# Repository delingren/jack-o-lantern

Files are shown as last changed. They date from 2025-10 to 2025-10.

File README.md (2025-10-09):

# Jack-O-Lantern (3d printed, powered by USB)

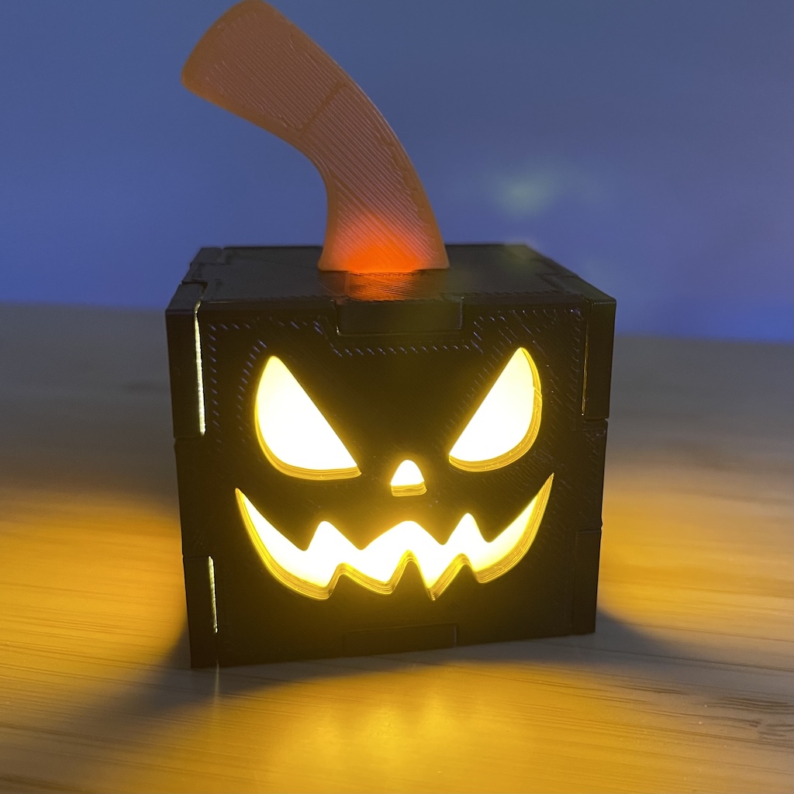
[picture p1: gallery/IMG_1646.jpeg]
black


## Parts:

* Soldering iron and tin
* 3D printer
* COB LED light [AliExpress](https://www.aliexpress.us/item/3256807134620275.html) | [Amazon](https://www.amazon.com/dp/B07DHB13J4)
* USB-C breakout board [AliExpress](https://www.aliexpress.us/item/3256809276708466.html) | [Amazon](https://www.amazon.com/dp/B0F2S1K5X8)
* 22 ohm resistor (or similar value)
* Orange vellum paper (if you print black)
* Double sided tape, super glue, paper glue, 
* Optinal: hot glue and glue gun

## Steps

There isn't much to it once you have 3d printed everything. 

0. 3D print all the pieces

1. Solder the resister, USB breakout board, and the LED together

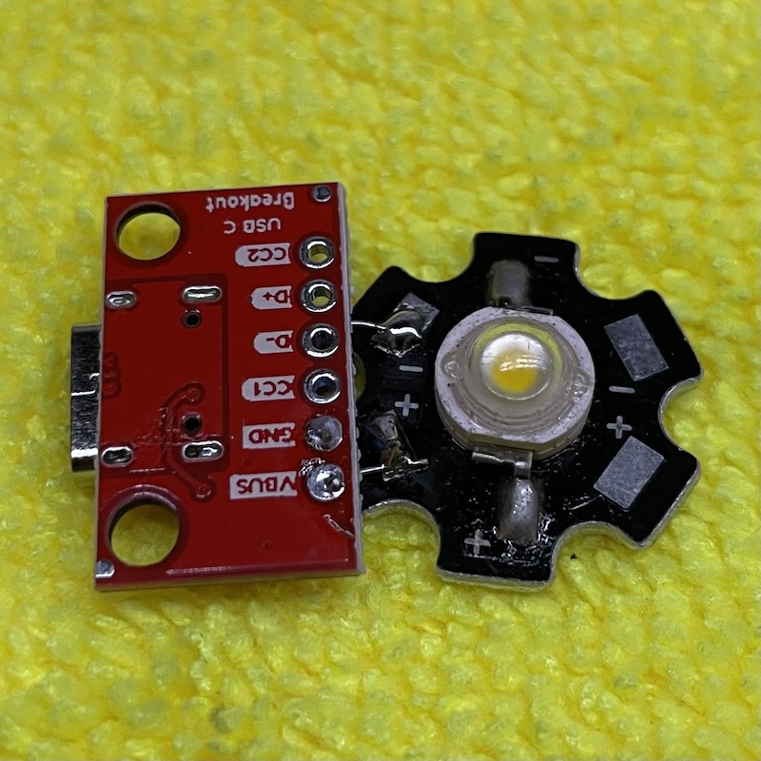
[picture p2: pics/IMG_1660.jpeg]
upside

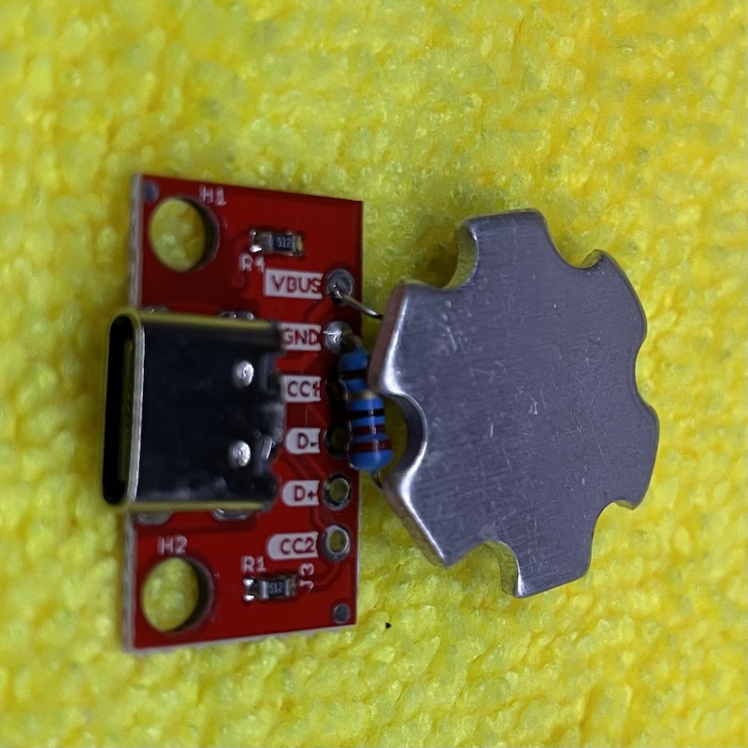
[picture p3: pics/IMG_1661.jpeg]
downside


2. Tape the LED down to the bottom piece and fit the USB C breakout board to the posts. Optionally, drip a couple of drops of hot glue on the posts.

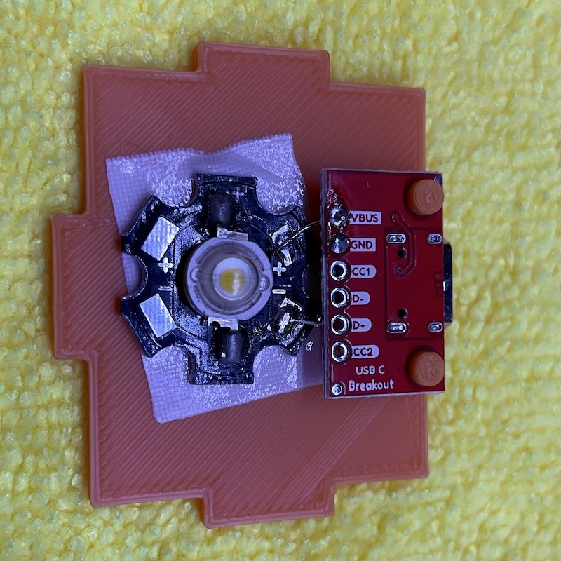
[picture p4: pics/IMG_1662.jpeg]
taped


3. Super glue the stem and the lid together. Hot glue doesn't work as well. B7000 works fine too.

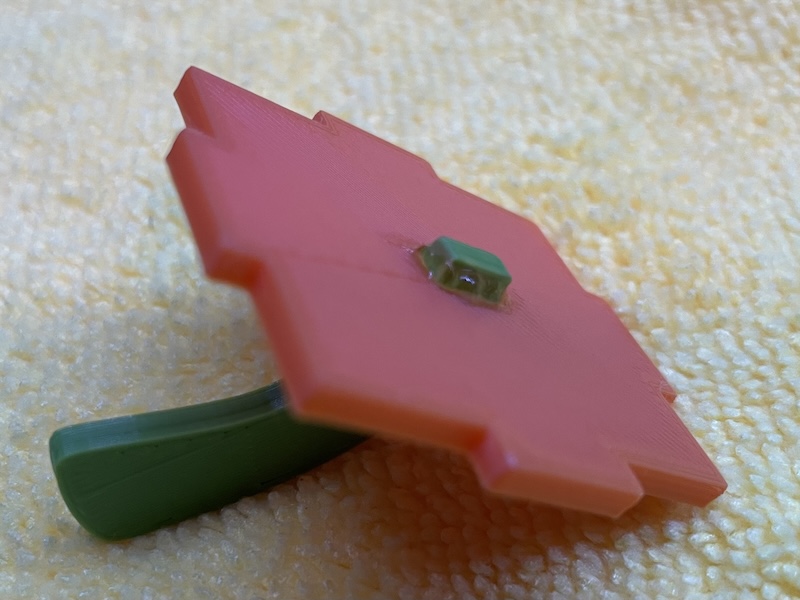
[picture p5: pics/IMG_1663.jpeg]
lid


## Notes:
* The LED I have is rated 1W at 3V. I wanted to use a 5V power source. So I added a 22 ohm resistor. The voltage is down to just about 3V and the current is about 90 mA. Not quite 1W but bright enough and the LED stays cool.
* I used a USB C breakout board as the power suppy. It has a couple of 5.1K resistors to trigger 5V so that it'd work with a PD charger in addition to basic dumb chargers. If you use a dumb USB C breakout board, it'll only work with a dumb charger. All USB-A chargers are dumb.
* The cube is printed in 7 pieces (one for the stem) and friction fitted together. If you don't want to fine tune the dimensions, make the gap big enough and use some hot glue.
* For the LED to shine through the patterns, I originally had them completely cut out, and it was terrible. Then I carve it down to 0.2mm, just one layer. It worked perfectly for orange filament, but not black. So I decided to cur the patterns out and laminate a piece of orange paper from inside.
* Since all pieces are friction fitted together, I had to adjust the dimensions of the tabs by trial and error. Eventually, a size difference of 0.6mm between the tabs and the notches worked well for my black filament. However, it was just a tad too big for my orange filament. So I parameterized it in Fusion 360, so that I can simply change one value when switching filaments. It turned out 0.4mm (0.2mm on either side) works well for this particular filament.

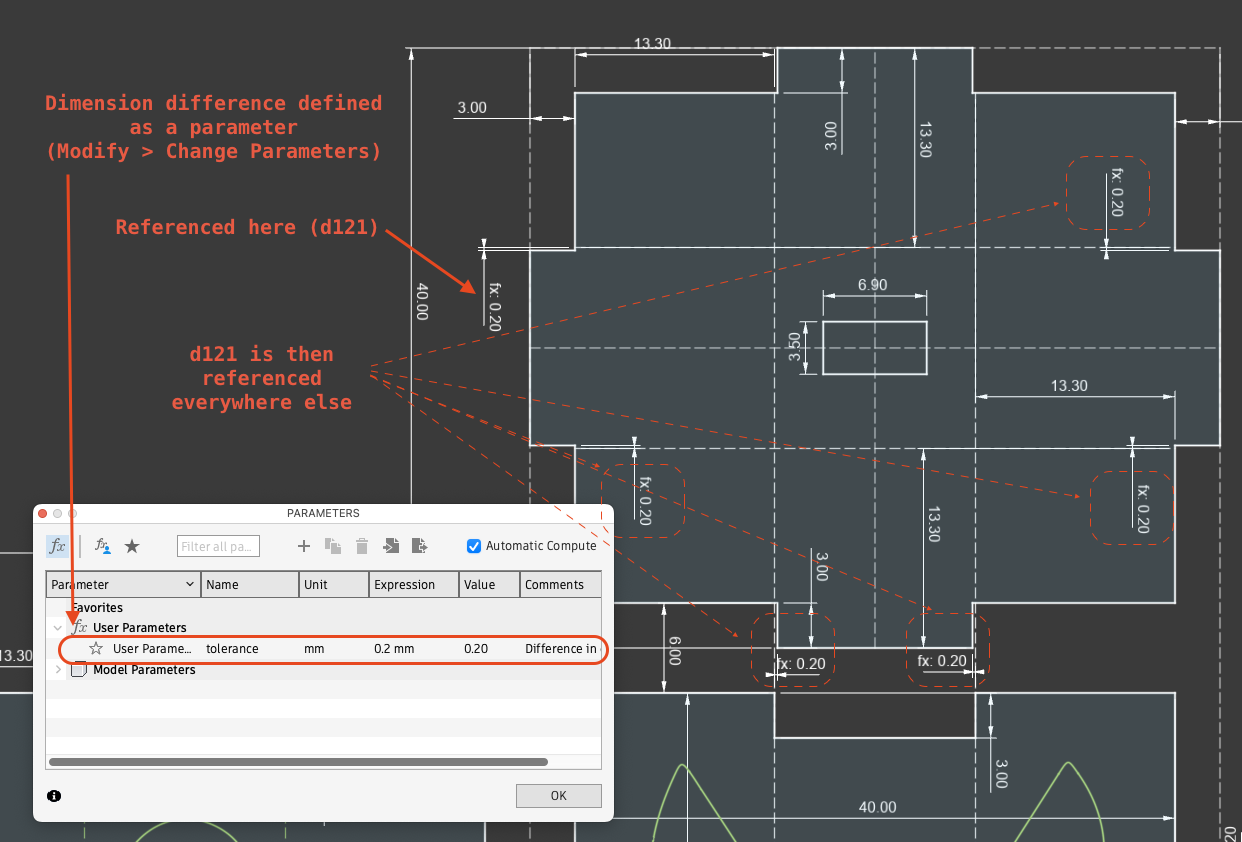
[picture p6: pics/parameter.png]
fusion360


## Downloads and gallery
* Find under this folder the `.f3d` file that you can open in fusion 360.
* Find under [`stls`](./stls/) for STLs. I created them for *my* orange and black filaments respectively. I.e. with tolerance set to 0.3 for black and 0.2 for orange. This may not work for your filament. Also, the black STLs have the patterns hollowed out, but not orange.
* [Here's](./gallery/) the gallery

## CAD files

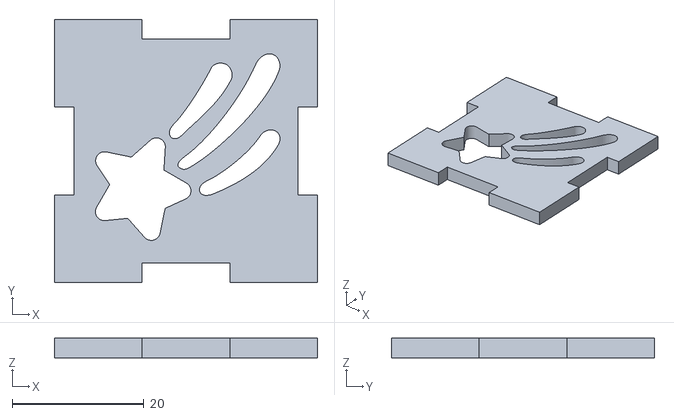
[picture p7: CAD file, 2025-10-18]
stls/black/shooting-star-2.stl
40.0 x 40.0 x 3.00

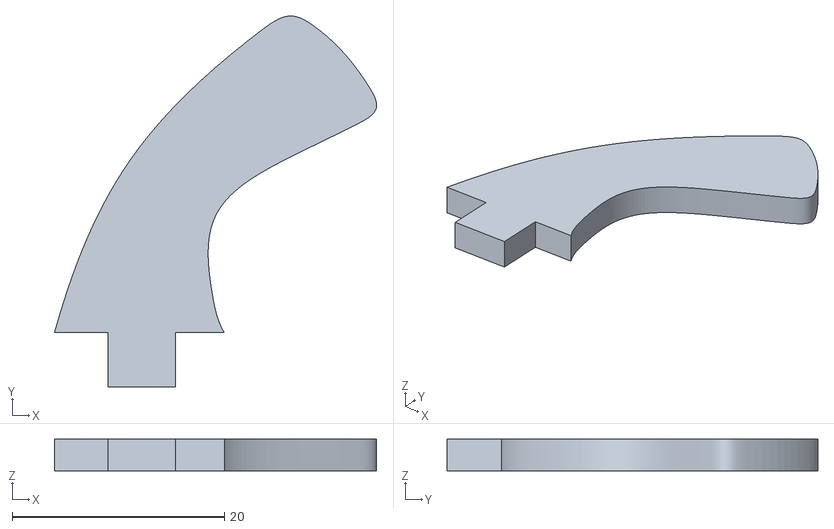
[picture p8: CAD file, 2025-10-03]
stls/orange-stem.stl
30.4 x 34.9 x 3.00

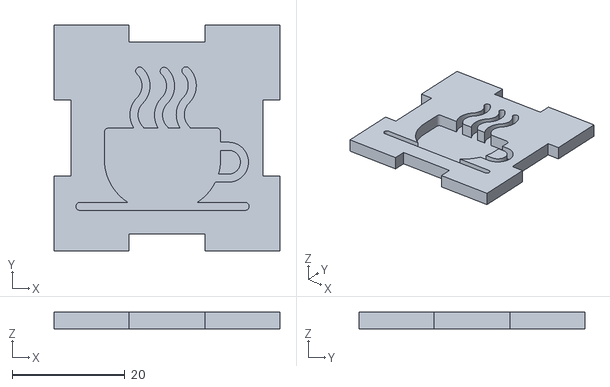
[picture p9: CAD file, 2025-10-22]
stls/orange/coffee.stl
40.0 x 40.0 x 3.00

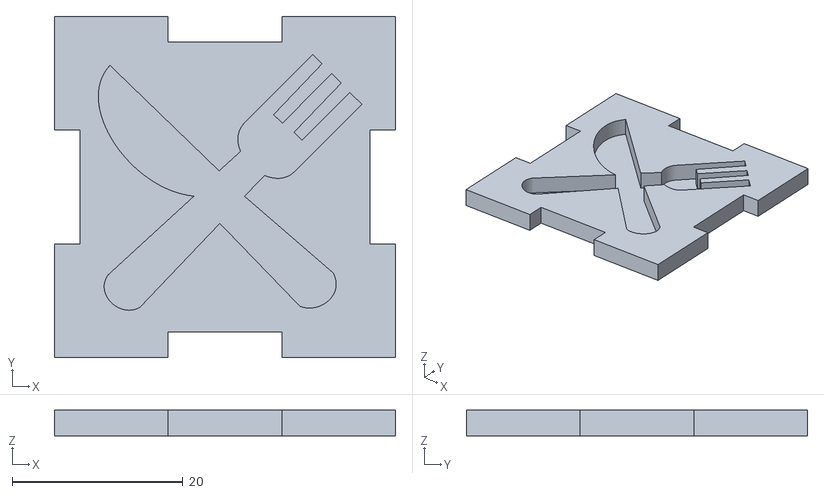
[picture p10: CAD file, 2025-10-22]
stls/orange/silverware.stl
40.0 x 40.0 x 3.00

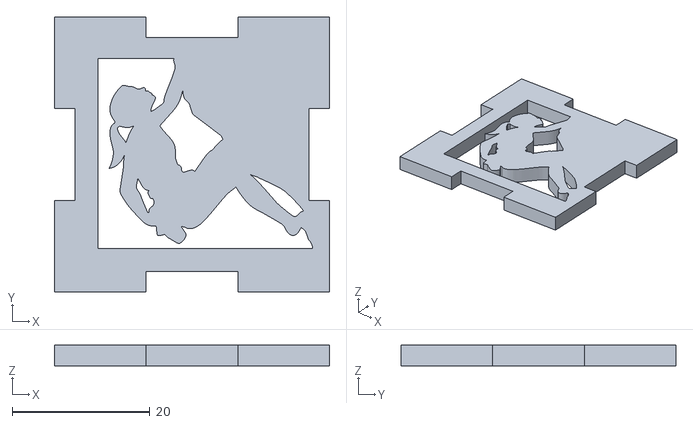
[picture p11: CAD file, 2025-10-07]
stls/black/climber.stl
40.0 x 40.0 x 3.00

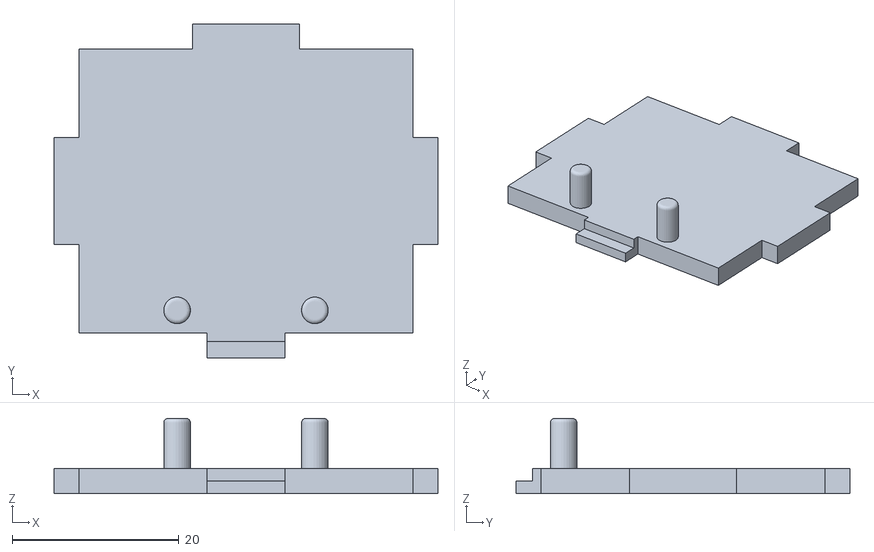
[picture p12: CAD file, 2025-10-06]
stls/black/bottom.stl
46.0 x 40.0 x 9.00

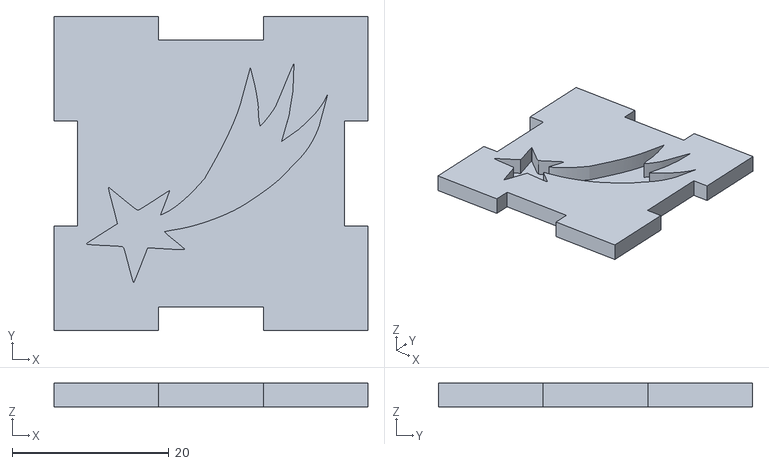
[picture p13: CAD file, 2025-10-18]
stls/orange/shooting-star-1.stl
40.0 x 40.0 x 3.00

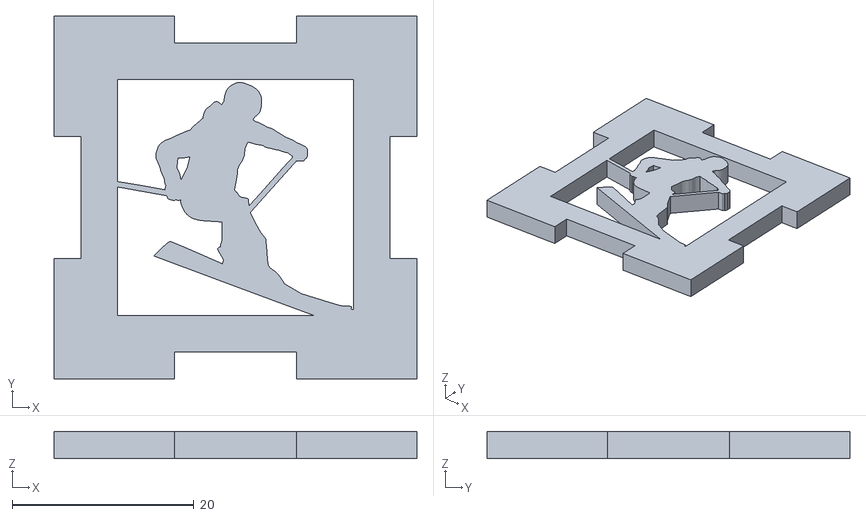
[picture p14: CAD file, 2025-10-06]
stls/black/skier.stl
40.0 x 40.0 x 3.00

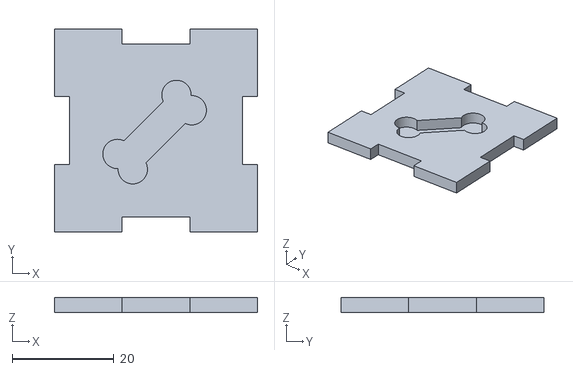
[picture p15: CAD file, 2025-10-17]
stls/orange/bone.stl
40.0 x 40.0 x 3.00

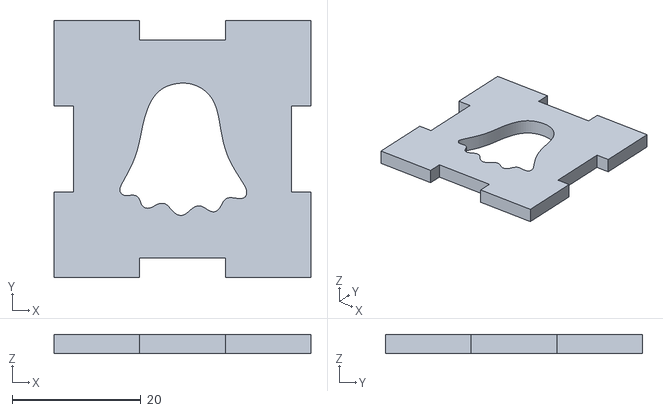
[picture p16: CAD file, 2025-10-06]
stls/black/ghost-1.stl
40.0 x 40.0 x 3.00

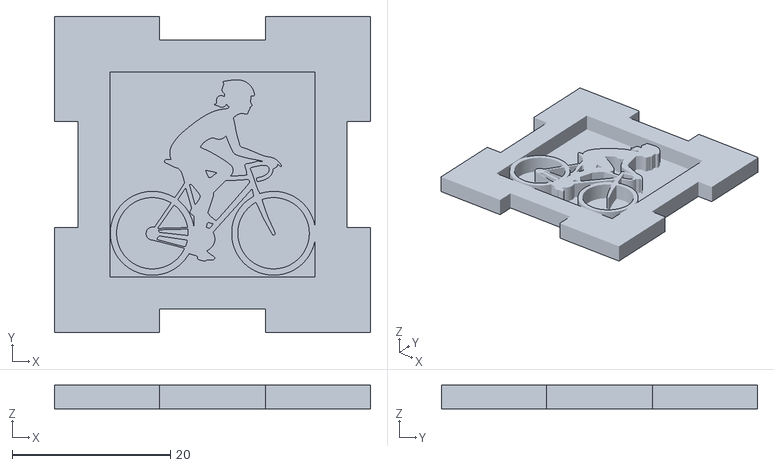
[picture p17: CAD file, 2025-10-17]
stls/orange/cyclist.stl
40.0 x 40.0 x 3.00

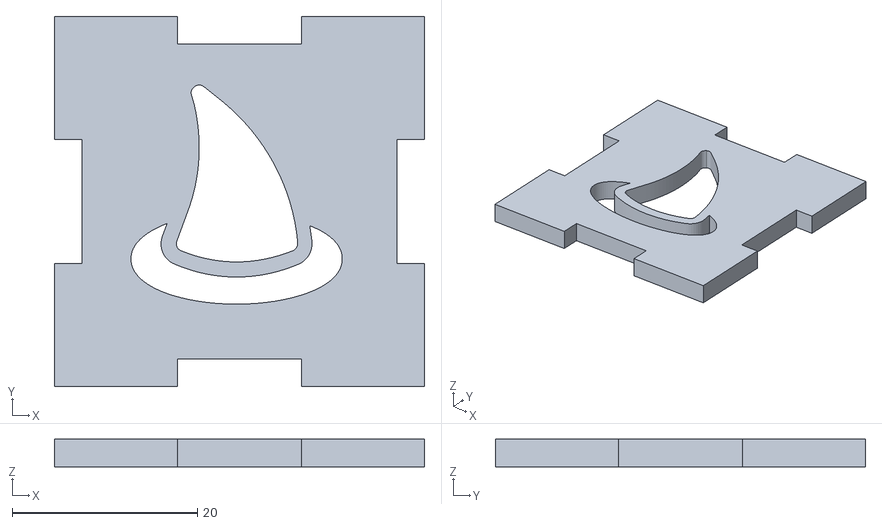
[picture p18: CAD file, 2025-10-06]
stls/black/hat.stl
40.0 x 40.0 x 3.00

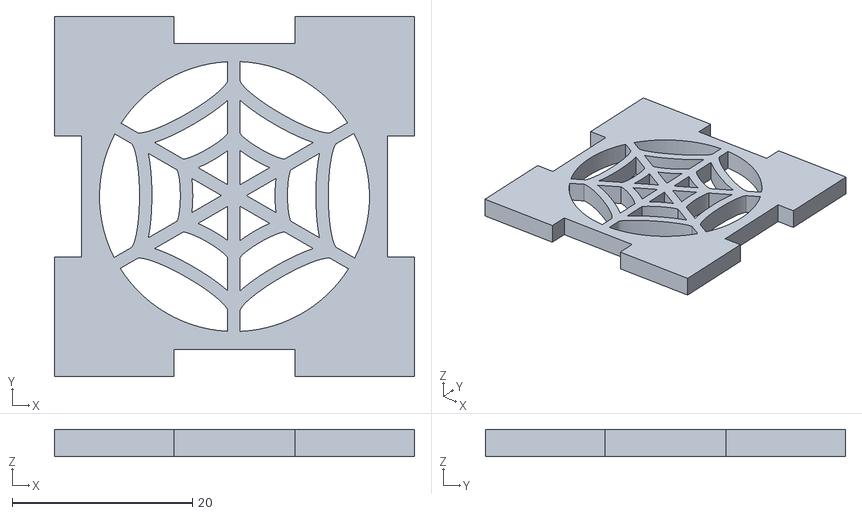
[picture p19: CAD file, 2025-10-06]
stls/black/web.stl
40.0 x 40.0 x 3.00

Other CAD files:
stls/black/shooting-star-1.stl
stls/orange/shooting-star-2.stl
stls/orange/paw.stl
stls/orange/barbell.stl
jack-o-lantern.f3d
stls/black/back.stl
stls/black/bat.stl
stls/black/face.stl
stls/black/ghost-2.stl
stls/black/top.stl
stls/orange/android.stl
stls/orange/back.stl
stls/orange/bat.stl
stls/orange/bottom.stl
stls/orange/climber.stl
stls/orange/face.stl
stls/orange/ghost-1.stl
stls/orange/ghost-2.stl
stls/orange/google.stl
stls/orange/hat.stl
stls/orange/quickshare.stl
stls/orange/skier.stl
stls/orange/top.stl
stls/orange/vw.stl
stls/orange/web.stl

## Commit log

2025-10-03 Update svg and stl files
    [back.stl, bat-hollow.stl, bat.stl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]
2025-10-04 Update stl files
    [back.stl, bat-hollow.stl, bottom.stl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]
2025-10-05 Update stl
    [orange-bottom.stl, orange-ghost-1.stl, orange-vw.stl]
2025-10-05 Update climber
    [black-back.stl, black-bottom.stl, black-face.stl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]
2025-10-06 Add some stencils and stls
    [black-bat.stl, black-ghost-1.stl, black-ghost-2.stl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]
2025-10-06 Make the posts a little smaller
    [black-bottom.stl]
2025-10-07 Update STLs, and 3d model
    [android.stl, back.stl, bat.stl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]
2025-10-08 Updated instructions and added pictures
    [jack-o-lantern.f3d]
2025-10-09 Update doc
    [bottom.stl]
2025-10-10 barbell svg and stl
    [barbell.stl]
2025-10-17 Update stls
    [bone.stl, cyclist.stl, paw.stl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]
2025-10-17 Update fusion360 file
    [jack-o-lantern.f3d]
2025-10-18 Update shooting star
    [shooting-star-1.stl, shooting-star-2.stl, shooting-star.stl]
2025-10-22 Add coffee and silverware
    [coffee.stl, silverware.stl]
